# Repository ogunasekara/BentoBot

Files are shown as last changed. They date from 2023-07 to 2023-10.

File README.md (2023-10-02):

# BentoBot

## Overview

Bentobot is a mobile robotics platform to test custom C++ ROS packages for mobile robot mapping, localization, and path planning. The two-wheel differential drive chassis was designed using [OnShape](https://www.onshape.com/en/) and 3D printed on the Ender 3 V2. All design and software artifacts will ultimately be included in this repository. The robot was designed to utilize off the shelf components that can be purchased online.

## Software Dependencies

- ROS Melodic
- Eigen3

## Remote Development Setup

I currently use the [Remote - SSH](https://marketplace.visualstudio.com/items?itemName=ms-vscode-remote.remote-ssh) VSCode extension to remotely develop on the robot. To use this, ensure SSH is setup on the robot and utilize Remote - SSH's connect to host to connect to the robot.

To ensure that C++ libraries show up properly in the remote development environment, install the [C/C++ Extension Pack](https://marketplace.visualstudio.com/items?itemName=ms-vscode.cpptools-extension-pack) on VSCode.

In the auto-generated `.vscode/c_pp_properties.json` file, ensure the includePath has the following directories:

```
${workspaceFolder}/**",
"<repository path>/devel/include/**",
"/opt/ros/melodic/include/**",
"/usr/include/**"
```

## PlatformIO Setup

I am utilizing PlatformIO as a convenient way to upload firmware to the Teensy 4.0 onboard BentoBot. All of the firmware is contained in the `src/firmware` folder. To upload

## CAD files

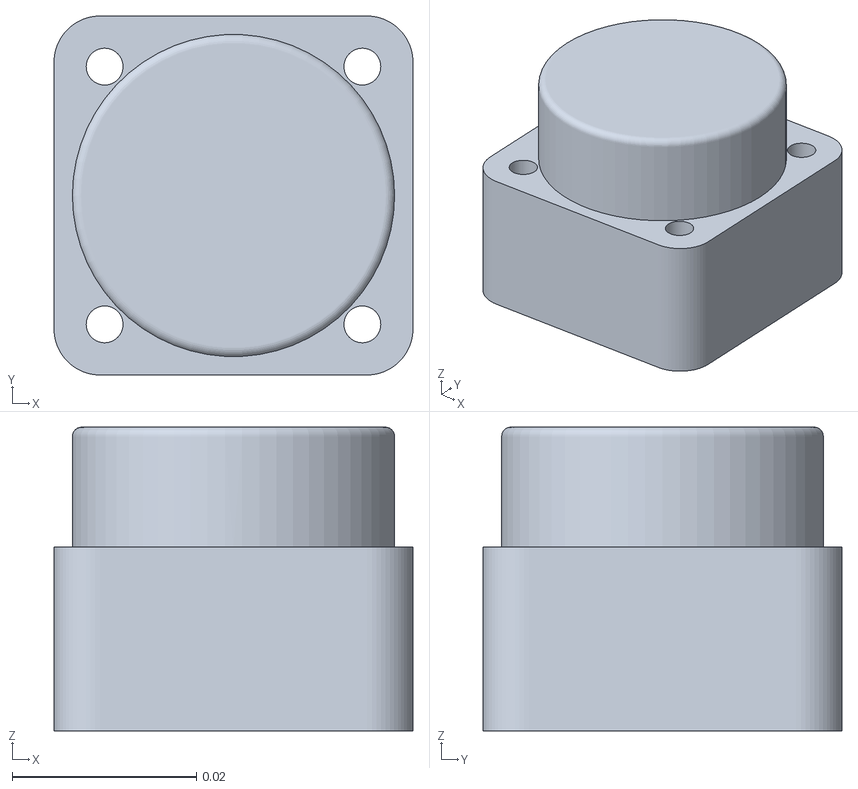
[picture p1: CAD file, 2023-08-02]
src/bentobot_description/urdf/meshes/lidar.stl
0.039 x 0.039 x 0.033

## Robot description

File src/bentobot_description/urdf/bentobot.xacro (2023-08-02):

<robot name="bentobot" xmlns:xacro="http://www.ros.org/wiki/xacro">

    <!-- gazebo integration -->

    <xacro:include filename="$(find bentobot_description)/urdf/bentobot.gazebo"/>

    <!-- xacro macros -->

    <xacro:macro name="caster_part" params="name origin_xyz">
        <collision name='${name}_collision'>
            <origin xyz="${origin_xyz}" rpy="0 0 0"/>
            <geometry>
                <sphere radius="0.01"/>
            </geometry>
        </collision>
    </xacro:macro>

    <xacro:macro name="wheel" params="name origin_xyz mesh_xyz">
        <link name="${name}">
            <pose>0 0 0 0 0 0</pose>
            <inertial>
                <mass value="1"/>
                <origin xyz="${origin_xyz}" rpy="0 0 0"/>
                <inertia ixx="0.0003" ixy="0" ixz="0" iyy="0.0003" iyz="0" izz="0.0006" />
            </inertial>
            <visual name="visual">
                <origin xyz="${mesh_xyz}" rpy="0 1.5707 1.5707"/>
                <geometry>
                    <mesh filename="package://bentobot_description/urdf/meshes/bentobot-wheel.dae"/>
                </geometry>
            </visual>
            <collision name="${name}_collision">
                <origin xyz="${origin_xyz}" rpy="0 1.5707 1.5707"/>
                <geometry>
                    <cylinder radius="0.034" length="0.027"/>
                </geometry>
            </collision>
        </link>
    </xacro:macro>

    <!-- root footprint link and joint -->

    <link name="robot_footprint"></link>

    <joint name="robot_footprint_joint" type="fixed">
        <origin xyz="0 0 0" rpy="0 0 0" />
        <parent link="robot_footprint"/>
        <child link="chassis" />m
    </joint>

    <!-- chassis link -->

    <link name="chassis">
        <pose>0 0 0 0 0 0</pose>

        <inertial>
            <mass value="5"/>
            <origin xyz="0 0 0" rpy="0 0 0"/>
            <inertia ixx="0.016" ixy="0" ixz="0" iyy="0.021" iyz="0" izz="0.019" />
        </inertial>

        <visual>
            <origin xyz="0 0 -0.065" rpy="0 0 -1.5707"/>
            <material name="blue">
                <color rgba="0.0 0.0 0.0 1.0"/>
            </material>
            <geometry>
                <mesh filename="package://bentobot_description/urdf/meshes/robot-chassis.stl"/>
            </geometry>
        </visual>

        <collision name="chassis_collision">
            <origin xyz="0 0 0" rpy="0 0 0"/> 
            <geometry>
                <box size="0.17 0.13 0.14"/>
            </geometry>
        </collision>

        <xacro:caster_part name="front_left_caster" origin_xyz="0.0575 0.0425 -0.075"/>
        <xacro:caster_part name="front_right_caster" origin_xyz="0.0575 -0.0425 -0.075"/>
        <xacro:caster_part name="back_left_caster" origin_xyz="-0.0575 0.0425 -0.075"/>
        <xacro:caster_part name="back_right_caster" origin_xyz="-0.0575 -0.0425 -0.075"/>
    </link>

    <!-- wheel links and joints -->

    <xacro:wheel name="left_wheel" origin_xyz="0 -0.0135 0" mesh_xyz="0 -0.027 0"/>
    <xacro:wheel name="right_wheel" origin_xyz="0 0.0135 0" mesh_xyz="0 0 0"/>

    <joint type="continuous" name="left_wheel_hinge">
    <origin xyz="0 0.092 -0.0513" rpy="0 0 0"/>
        <child link="left_wheel"/>
        <parent link="chassis"/>
        <axis xyz="0 1 0" rpy="0 0 0"/>
        <limit effort="10000" velocity="10000"/>
        <dynamics damping="1.0" friction="1.0"/>
    </joint>

    <joint type="continuous" name="right_wheel_hinge">
        <origin xyz="0 -0.092 -0.0513" rpy="0 0 0"/>
        <child link="right_wheel"/>
        <parent link="chassis"/>
        <axis xyz="0 1 0" rpy="0 0 0"/>
        <limit effort="10000" velocity="10000"/>
        <dynamics damping="1.0" friction="1.0"/>
    </joint>

    <!-- lidar link and joint -->

    <link name="lidar">
        <pose>0 0 0 0 0 0</pose>

        <inertial>
            <mass value="1e-5"/>
            <origin xyz="0 0 0" rpy="0 0 0"/>
            <inertia ixx="1e-6" ixy="0" ixz="0" iyy="1e-6" iyz="0" izz="1e-6" />
        </inertial>

        <visual>
            <origin xyz="0 0 -0.0165" rpy="0 0 0"/>
            <geometry>
                <mesh filename="package://bentobot_description/urdf/meshes/lidar.stl"/>
            </geometry>
        </visual>

        <collision name="lidar_collision">
            <geometry>
                <box size="0.039 0.039 0.033"/>
            </geometry>
        </collision>
    </link>

    <joint type="fixed" name="lidar_joint">
        <origin xyz="0.06 0 0.0865" rpy="0 0 0"/>
        <child link="lidar"/>
        <parent link="chassis"/>
        <axis xyz="0 1 0" rpy="0 0 0"/>
    </joint>

     <!-- Set link colors -->

    <gazebo reference="chassis">
        <material>Gazebo/DarkGrey</material>
    </gazebo>

    <gazebo reference="lidar">
        <material>Gazebo/DarkGrey</material>
    </gazebo>
</robot>

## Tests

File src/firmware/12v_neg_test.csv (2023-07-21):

ang_vel | motor_cmd
-1.5064583333333348 | -255
-1.5295104895104905 | -250
-1.5136111111111117 | -245
-1.5038461538461534 | -240
-1.4947222222222225 | -235
-1.4870629370629374 | -230
-1.4833333333333325 | -225
-1.4746153846153836 | -220
-1.4681249999999988 | -215
-1.455524475524476 | -210
-1.4527083333333328 | -205
-1.4400694444444426 | -200
-1.4329166666666662 | -195
-1.4211888111888111 | -190
-1.4178472222222216 | -185
-1.4002777777777768 | -180
-1.3921678321678324 | -175
-1.380069444444445 | -170
-1.3619444444444462 | -165
-1.3452777777777776 | -160
-1.332986111111112 | -155
-1.3169930069930067 | -150
-1.2978620689655178 | -145
-1.279722222222223 | -140
-1.2617361111111112 | -135
-1.2409027777777775 | -130
-1.2172222222222209 | -125
-1.185862068965516 | -120
-1.1564583333333327 | -115
-1.1275694444444442 | -110
-1.0943448275862075 | -105
-1.0560689655172426 | -100
-1.0140689655172417 | -95
-0.9719310344827579 | -90
-0.9204109589041107 | -85
-0.8636301369863005 | -80
-0.8001369863013706 | -75
-0.7347945205479449 | -70
-0.6585714285714287 | -65
-0.5701369863013697 | -60
-0.48312925170068005 | -55
-0.3811564625850337 | -50
-0.27659863945578256 | -45
-0.1673648648648647 | -40
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

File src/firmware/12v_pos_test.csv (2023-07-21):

ang_vel | motor_cmd
1.4954861111111108 | 255
1.515347222222223 | 250
1.4968531468531463 | 245
1.4918055555555556 | 240
1.4854166666666664 | 235
1.47188811188811 | 230
1.467499999999999 | 225
1.4603472222222222 | 220
1.4524475524475529 | 215
1.4452777777777763 | 210
1.437222222222222 | 205
1.4276223776223778 | 200
1.4193749999999992 | 195
1.420902777777777 | 190
1.4027083333333321 | 185
1.3949305555555551 | 180
1.3811111111111103 | 175
1.3736363636363642 | 170
1.3593793103448282 | 165
1.3438194444444447 | 160
1.3306250000000015 | 155
1.313611111111111 | 150
1.298750000000001 | 145
1.2795833333333337 | 140
1.2655555555555558 | 135
1.2415172413793103 | 130
1.2179861111111103 | 125
1.189103448275861 | 120
1.1609027777777774 | 115
1.131103448275862 | 110
1.0953793103448284 | 105
1.0665517241379308 | 100
1.015448275862069 | 95
0.968082191780821 | 90
0.9175342465753431 | 85
0.8627397260273967 | 80
0.7960958904109593 | 75
0.7286986301369851 | 70
0.6541095890410962 | 65
0.5706122448979588 | 60
0.48176870748299266 | 55
0.3853741496598635 | 50
0.2858108108108113 | 45
0.17829931972789106 | 40
0.06101351351351332 | 35
0.00174496644295302 | 30
0.0 | 25
0.0 | 20
-0.00013513513513513514 | 15
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

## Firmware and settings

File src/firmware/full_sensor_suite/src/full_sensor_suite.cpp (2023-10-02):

#include <BasicLinearAlgebra.h>
#include <Adafruit_MPU6050.h>
#include <MotorKalmanFilter.h>
#include <MotorPID.h>

/*--- IMU ---*/

#define MPU_ROT_X_OFFSET 0.0582
#define MPU_ROT_Y_OFFSET -0.0037
#define MPU_ROT_Z_OFFSET 0.0461

Adafruit_MPU6050 mpu;

void initializeIMU() {
  // initialize IMU
  if (!mpu.begin()) {
    Serial.println("Failed to initialize MPU-6050 chip");
    while (1) {
      delay(10);
    }
  }

  // set desired properties for sensor
  mpu.setAccelerometerRange(MPU6050_RANGE_16_G);
  mpu.setGyroRange(MPU6050_RANGE_250_DEG);
  mpu.setFilterBandwidth(MPU6050_BAND_21_HZ);
  delay(100);
}

/*--- MOTOR ENCODERS ---*/

// left motor
#define MOTOR1_ENCA 11
#define MOTOR1_ENCB 12
#define MOTOR1_IN1 6
#define MOTOR1_IN2 5
#define MOTOR1_PWM 7

// right motor
#define MOTOR2_ENCA 10
#define MOTOR2_ENCB 9
#define MOTOR2_IN1 4
#define MOTOR2_IN2 3
#define MOTOR2_PWM 2

#define TICKS_PER_REV 680.0 // found through experimentation
#define WHEEL_DIAMETER 0.068
#define WHEEL_BASE_LENGTH 0.16

volatile long motor1_enc_count = 0;
volatile long motor2_enc_count = 0;

void handleMotor1EncAChange() {
  int encA = digitalRead(MOTOR1_ENCA);
  int encB = digitalRead(MOTOR1_ENCB);

  if (encA == HIGH) {
    if (encB == HIGH) {
      motor1_enc_count += 1;
    } else {
      motor1_enc_count -= 1;
    }
  } else {
    if (encB == HIGH) {
      motor1_enc_count -= 1;
    } else {
      motor1_enc_count += 1;
    }
  }
}

void handleMotor1EncBChange() {
  int encA = digitalRead(MOTOR1_ENCA);
  int encB = digitalRead(MOTOR1_ENCB);

  if (encB == HIGH) {
    if (encA == LOW) {
      motor1_enc_count += 1;
    } else {
      motor1_enc_count -= 1;
    }
  } else {
    if (encA == LOW) {
      motor1_enc_count -= 1;
    } else {
      motor1_enc_count += 1;
    }
  }
}

void handleMotor2EncAChange() {
  int encA = digitalRead(MOTOR2_ENCA);
  int encB = digitalRead(MOTOR2_ENCB);

  if (encA == HIGH) {
    if (encB == HIGH) {
      motor2_enc_count += 1;
    } else {
      motor2_enc_count -= 1;
    }
  } else {
    if (encB == HIGH) {
      motor2_enc_count -= 1;
    } else {
      motor2_enc_count += 1;
    }
  }
}

void handleMotor2EncBChange() {
  int encA = digitalRead(MOTOR2_ENCA);
  int encB = digitalRead(MOTOR2_ENCB);

  if (encB == HIGH) {
    if (encA == LOW) {
      motor2_enc_count += 1;
    } else {
      motor2_enc_count -= 1;
    }
  } else {
    if (encA == LOW) {
      motor2_enc_count -= 1;
    } else {
      motor2_enc_count += 1;
    }
  }
}

/*--- MOTOR KF AND CONTROLLER ---*/

MotorKalmanFilter motor1_filter = MotorKalmanFilter();
MotorPID motor1_pid = MotorPID(MOTOR1_IN1, MOTOR1_IN2, MOTOR1_PWM, 300.0, 100.0, 0.0, 64.4, 0.807);

MotorKalmanFilter motor2_filter = MotorKalmanFilter();
MotorPID motor2_pid = MotorPID(MOTOR2_IN1, MOTOR2_IN2, MOTOR2_PWM, 300.0, 100.0, 0.0, 71.2, 0.774);

/*--- INPUT PARSER ---*/

// input: "[v] [w]\n" where [v] is linear vel and [w] is angular vel

String cmd;
void parseInput() {
  if (Serial.available()) {
    cmd = Serial.readStringUntil('\n');
    cmd.trim();
    Serial.println(cmd);

    int ind = cmd.indexOf(' ');
    if ( ind == -1 ) { return; }

    double lin_vel = cmd.substring(0, ind).toFloat();
    double ang_vel = cmd.substring(ind + 1).toFloat();

    double left_vel = (2.0 * lin_vel - WHEEL_BASE_LENGTH * ang_vel) / 2.0;
    double right_vel = (2.0 * lin_vel + WHEEL_BASE_LENGTH * ang_vel) / 2.0;

    motor1_pid.setVel(left_vel);
    motor2_pid.setVel(right_vel);
  }
}

/*--- MAIN LOOP ---*/

void setup() {
  // setup encoder pins
  pinMode(MOTOR1_ENCA, INPUT);
  pinMode(MOTOR1_ENCB, INPUT);
  attachInterrupt(digitalPinToInterrupt(MOTOR1_ENCA), handleMotor1EncAChange, CHANGE);
  attachInterrupt(digitalPinToInterrupt(MOTOR1_ENCB), handleMotor1EncBChange, CHANGE);

  pinMode(MOTOR2_ENCA, INPUT);
  pinMode(MOTOR2_ENCB, INPUT);
  attachInterrupt(digitalPinToInterrupt(MOTOR2_ENCA), handleMotor2EncAChange, CHANGE);
  attachInterrupt(digitalPinToInterrupt(MOTOR2_ENCB), handleMotor2EncBChange, CHANGE);

  // initialize serial and wait to open
  Serial.begin(115200);
  while (!Serial) { ; }

  // initialize motors
  motor1_pid.begin();
  motor2_pid.begin();

  // initialize IMU
  initializeIMU();
}

void loop() {
  // initialize encoder count
  double prev_motor1_enc = motor1_enc_count;
  double prev_motor2_enc = motor2_enc_count;
  double motor1_vel, motor2_vel;
  double lin_vel, ang_vel;

  // initialize timer
  long prev_time = millis();
  double dt;

  /* Get new sensor events with the readings */
  sensors_event_t a, g, temp;

  // update state at 100 hz
  for (;;) {
    dt = (double)(millis() - prev_time) / 1000.0;
    prev_time = millis();

    // parse any incoming input
    parseInput();

    // filter update
    motor1_filter.update(dt, motor1_enc_count - prev_motor1_enc);
    motor2_filter.update(dt, motor2_enc_count - prev_motor2_enc);

    // controller update
    motor1_vel = motor1_filter.getVel();
    motor2_vel = motor2_filter.getVel();
    motor1_pid.update(dt, motor1_vel);
    motor2_pid.update(dt, motor2_vel);

    // reset enc counts
    prev_motor1_enc = motor1_enc_count;
    prev_motor2_enc = motor2_enc_count;

    lin_vel = (motor2_vel + motor1_vel) / 2.0;
    ang_vel = (motor2_vel - motor1_vel) / WHEEL_BASE_LENGTH;

    // get IMU information
    mpu.getEvent(&a, &g, &temp);

    Serial.print(motor1_vel);
    Serial.print(" ");
    Serial.print(motor2_vel);
    Serial.print(" ");
    Serial.println(g.gyro.z + MPU_ROT_Z_OFFSET);

    delay(10);
  }
}

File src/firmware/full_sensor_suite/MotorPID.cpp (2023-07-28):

#include "Arduino.h"
#include "MotorPID.h"

#define PWM_MIN 10
#define PWM_MAX 255
#define INTEGRAL_DECAY 0.01


MotorPID::MotorPID(
  unsigned int MOTOR_IN1,
  unsigned int MOTOR_IN2,
  unsigned int MOTOR_PWM,
  double PID_P,
  double PID_I,
  double PID_D,
  double FF_A,
  double FF_B):
  MOTOR_IN1 { MOTOR_IN1 },
  MOTOR_IN2 { MOTOR_IN2 },
  MOTOR_PWM { MOTOR_PWM },
  PID_P { PID_P },
  PID_I { PID_I },
  PID_D { PID_D },
  FF_A { FF_A },
  FF_B { FF_B }
{}

void MotorPID::begin() {
  // setup motor pins
  pinMode(MOTOR_IN1, OUTPUT);
  pinMode(MOTOR_IN2, OUTPUT);
  pinMode(MOTOR_PWM, OUTPUT);
  
  // ensure motors are not moving
  digitalWrite(MOTOR_IN1, LOW);
  digitalWrite(MOTOR_IN2, LOW);
  analogWrite(MOTOR_PWM, 0);
}

void MotorPID::update(double dt, double cur_vel) {
  if (abs(vel_target) > 0) {
    diff = (vel_target - cur_vel);

    derivative = diff / dt;
    integral += diff * dt;  // TODO: incorporate decay into this term

    feed_forward = FF_A * exp(FF_B * abs(vel_target)); // calculated experimentally and fitted to exponential
    feed_forward = (vel_target / abs(vel_target)) * feed_forward; // match sign with vel_target

    motor_cmd = ((feed_forward) + (PID_P * diff) + (PID_I * integral) + (PID_D * derivative));
    motor_cmd = (motor_cmd / abs(motor_cmd)) * min(PWM_MAX, abs(motor_cmd));  // upper bound
  } else {
    motor_cmd = 0;
  }

    driveMotor(motor_cmd);
}

void MotorPID::setVel(double vel) {
  vel_target = vel;
}

void MotorPID::driveMotor(int motor_cmd) {
  // stop motor if motor cmd too low
  if (abs(motor_cmd) <= PWM_MIN) {
    digitalWrite(MOTOR_IN1, LOW);
    digitalWrite(MOTOR_IN2, LOW);
  } else if (motor_cmd > 0) {
    digitalWrite(MOTOR_IN1, HIGH);
    digitalWrite(MOTOR_IN2, LOW);
    analogWrite(MOTOR_PWM, abs(motor_cmd));
  } else if (motor_cmd < 0) {
    digitalWrite(MOTOR_IN1, LOW);
    digitalWrite(MOTOR_IN2, HIGH);
    analogWrite(MOTOR_PWM, abs(motor_cmd));
  }
}

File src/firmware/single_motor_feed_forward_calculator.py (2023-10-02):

import serial
import threading
import time
import csv

FILE_PREFIX = "left_wheel_new"

ser = serial.Serial('/dev/ttyACM0', 115200, timeout=1)
data = [] # list of dicts, fields are motor_cmd, ang_vel

#--- READING AND PARSING ---#

vel_sum = 0
vel_cnt = 0

# thread to read serial continuously for parsing purposes
def read_serial():
    global vel_sum
    global vel_cnt

    while True:
        try:
            line = ser.readline().decode()
            measurement = parse_line(line)

            vel_sum += measurement # add target measurements
            vel_cnt += 1

            #print(measurements)
        except UnicodeDecodeError:
            pass

# daemon thread will close on end of main thread
read_thread = threading.Thread(target=read_serial, daemon=True)
read_thread.start()

def parse_line(line):
    line = line.strip()
    return float(line)

def reset_avg_vel():
    global vel_sum
    global vel_cnt
    
    vel_sum = 0
    vel_cnt = 0

def get_avg_vel():
    global vel_sum
    global vel_cnt

    return (vel_sum * 1.0) / (vel_cnt * 1.0) 

#--- COMMANDS ---#

def set_motor_pwm(pwm):
    s = str(pwm) + '\n'
    ser.write(s.encode())
    time.sleep(0.05)

def save_to_csv(filename, data):
    filename = FILE_PREFIX + "_" + filename
    fieldnames = {'motor_cmd', 'ang_vel'}

    with open(filename, 'w', newline='') as csvfile:
        writer = csv.DictWriter(csvfile, fieldnames=fieldnames)
        writer.writeheader()
        for row in data:
            writer.writerow(row)

#--- MAIN LOOP ---#

try:
    set_motor_pwm(0)

    print("waiting 5 seconds before negative")
    time.sleep(5)

    print("starting positive loop")
    # start from top and go down
    for cmd in range(-255, 0, 5):
        print("cmd: ", cmd)
        reset_avg_vel()
        set_motor_pwm(cmd)
        time.sleep(2)
        avg_vel = get_avg_vel()
        data.append({'motor_cmd': cmd, 'ang_vel': avg_vel})
        print("avg_vel: ", avg_vel)

    set_motor_pwm(0)
    print("waiting 5 seconds before positive")
    time.sleep(5)

    for cmd in range(255, 0, -5):
        print("cmd: ", cmd)
        reset_avg_vel()
        set_motor_pwm(cmd)
        time.sleep(2)
        avg_vel = get_avg_vel()
        data.append({'motor_cmd': cmd, 'ang_vel': avg_vel})
        print("avg_vel: ", avg_vel)

    set_motor_pwm(0)

    save_to_csv('test.csv', data)

except KeyboardInterrupt:
    ser.close()

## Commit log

2023-07-19 add lidar support
2023-07-20 add motor control test
2023-07-20 add single motor encoder test
2023-07-20 add single motor filter test
2023-07-20 add single motor pid test
2023-07-21 better ff approximation
    [12v_neg_test.csv, 12v_pos_test.csv]
2023-07-24 update to teensy breadboard
2023-07-24 add imu reading test
2023-07-28 add full sensor suite
2023-08-01 add xacro robot description
    [bentobot.xacro]
2023-08-02 add meshes and lidar
    [bentobot.xacro, lidar.stl]
2023-08-08 add motor calibration code
    [left_wheel_test.csv, right_wheel_test.csv]
2023-08-08 update pid tuning
2023-10-02 fix kalman filter
    [left_wheel_new_test.csv, right_wheel_new_test.csv]
2026-10-30 add single motor low pass filter test for velocity estimation
2026-10-30 support teensy-cli uploading, set PWM frequency to 20kHz
2026-10-30 calibrate motors for LPF velocity calculation
2026-11-03 add MotorModel feedforward to full_sensor_suite PID
    Replace the exponential feed forward in MotorPID with a MotorModel
    (cutoff + slope per motor). Clamp the PWM command to 255 and zero it
    below the model cutoff, and use the same cutoff as the driveMotor
    deadband. Fix MotorModel::getPWMFeedForward overwriting its cutoff.
2026-11-03 use MotorModel feedforward in single_motor_calibration
    Sync MotorPID/MotorModel from full_sensor_suite and run the controller
    in the sketch: serial input is now a target wheel velocity in m/s.
2026-11-03 add MotorLowPassFilter and use it for wheel velocity
    New low pass filter class matching single_motor_velocity_lpf_test, with
    the same update/getVel interface as MotorKalmanFilter. Switch
    full_sensor_suite and single_motor_calibration to it; the Kalman filter
    class is kept.
2026-11-03 set motor PWM frequency to 20kHz in MotorPID::begin
    The feed forward model was calibrated at 20kHz, but only the lpf test
    sketch set it; the other sketches ran at the Teensy default.
2026-11-03 ramp MotorPID velocity target with a max acceleration
    setVel now sets a goal; update moves the working target toward it by at
    most max_accel * dt (default 1.5 m/s^2) to avoid jumping at the start.
2026-11-03 reset MotorPID integral on stop and direction change
    Clear the integral when the ramped target is zero or crosses zero so
    stale accumulated error doesn't bias the next move.
2026-11-03 update PID constants in test
2026-11-03 use tuned PID constants in full_sensor_suite
    Match the P/I/D values tested in single_motor_calibration.
